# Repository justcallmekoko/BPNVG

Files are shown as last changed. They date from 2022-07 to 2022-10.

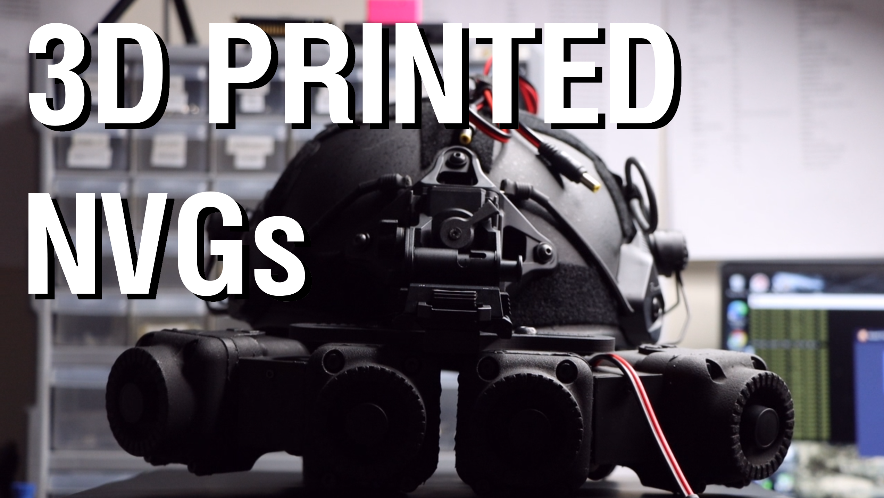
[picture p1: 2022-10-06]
BPNVG/images/thumnail1 - Copy.png

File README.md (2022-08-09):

# BPNVG

 This is the development repository for the PBNVG-project and all derivatives for joint development.
 
 We will also try to maintain extensive documentation of the project.

For more information and assembly instructions, check out the [wiki](https://github.com/justcallmekoko/BPNVG/wiki/bpnvg-v2-by-stubbs)

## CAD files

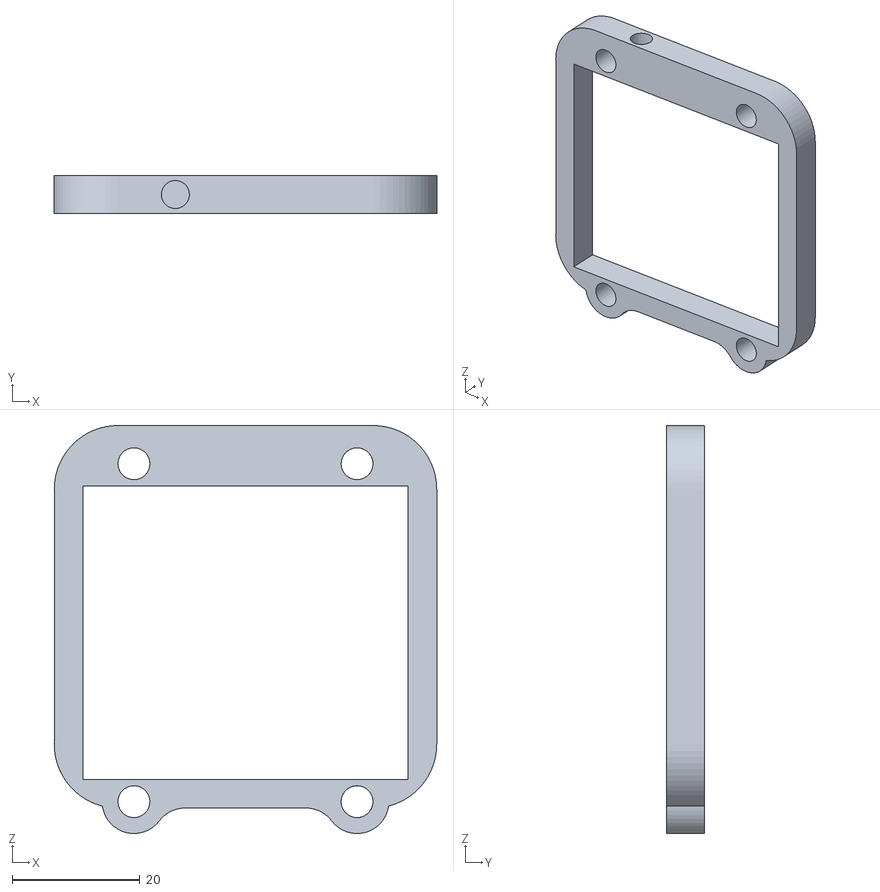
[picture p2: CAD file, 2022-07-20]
BPNVG/STLs/Gasket-Spacer_v3.stl
60.0 x 6.00 x 64.0

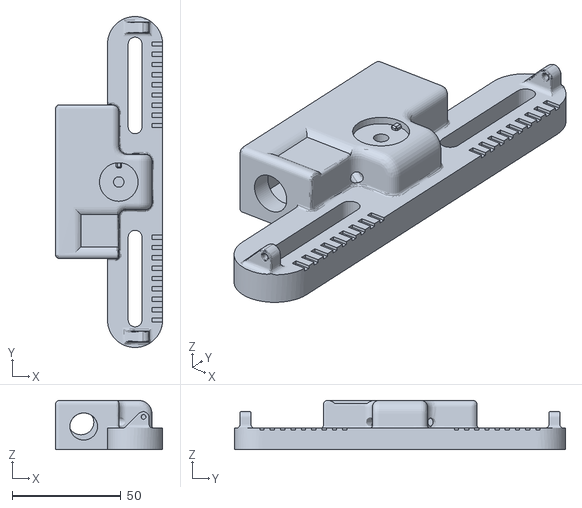
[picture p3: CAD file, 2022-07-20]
BPNVG/STLs/Powered Bridge_v3.3.stl
49.4 x 152.4 x 22.6

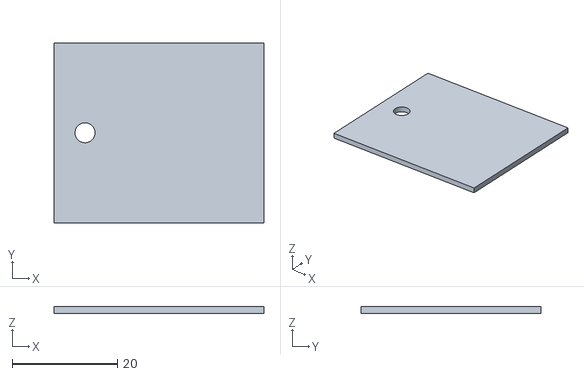
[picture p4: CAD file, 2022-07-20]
BPNVG/STLs/pano_COVER.stl
40.0 x 34.3 x 1.25

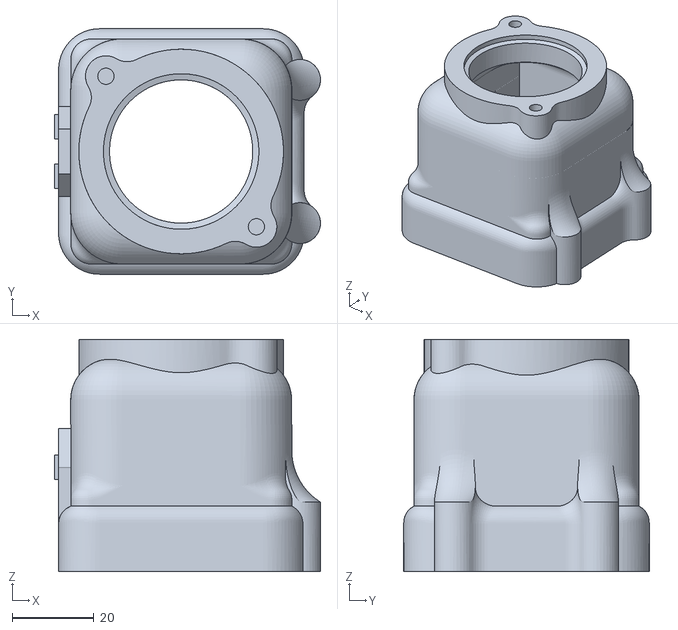
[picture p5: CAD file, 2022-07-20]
BPNVG/STLs/BPNVG_II_Single_monacle_body_SHORTY.stl
65.0 x 60.0 x 56.8

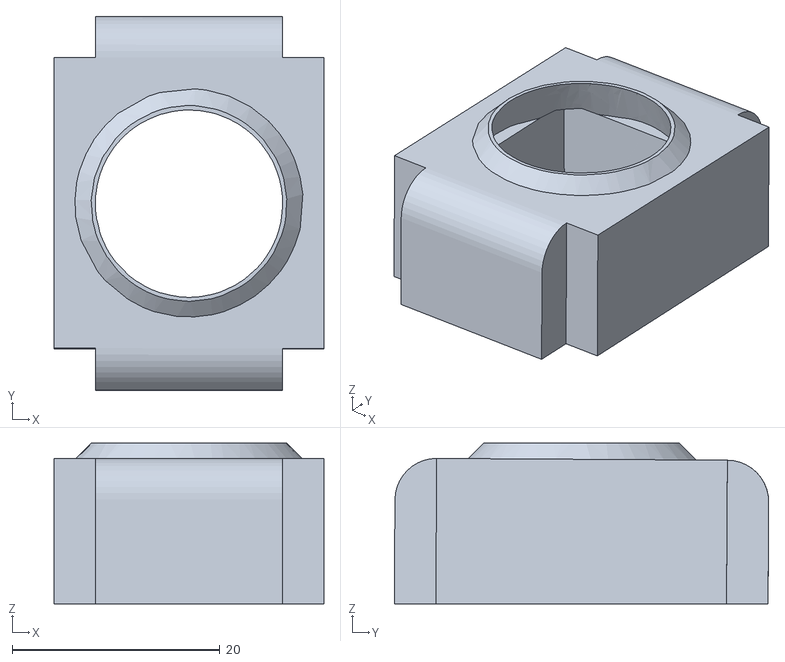
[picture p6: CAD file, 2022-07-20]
BPNVG/STLs/BPNVG Sensor Adaptor Night Cat 3 Fixed.stl
26.0 x 36.1 x 15.5

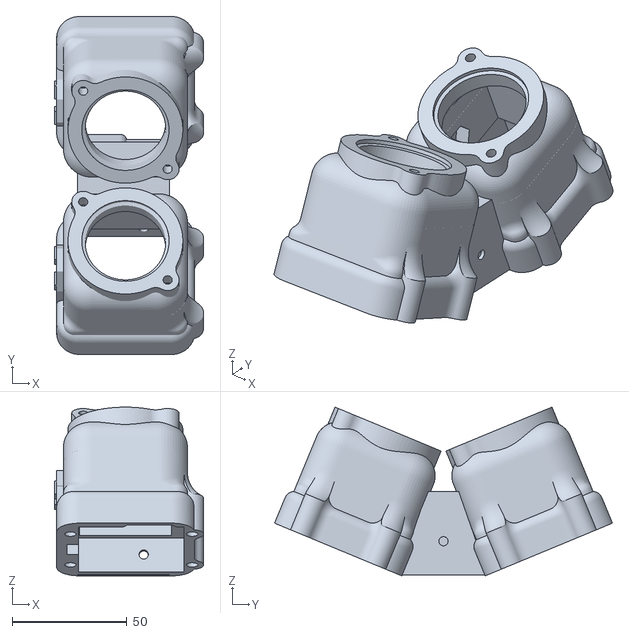
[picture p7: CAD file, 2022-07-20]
BPNVG/STLs/panoPANOpano.stl
65.0 x 147.1 x 73.5

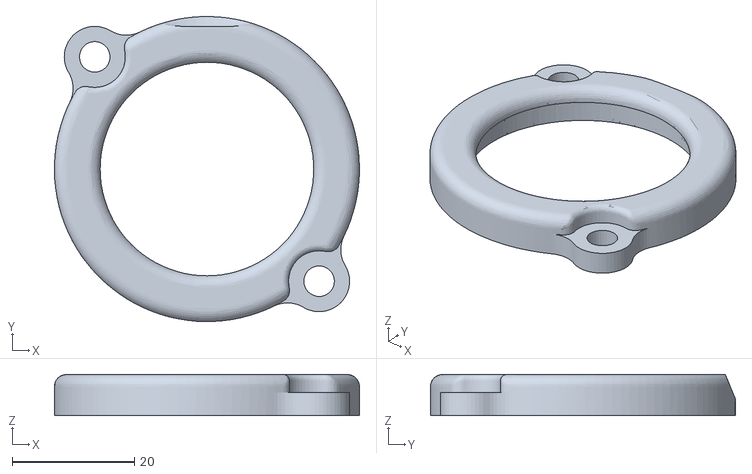
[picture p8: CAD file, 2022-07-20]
BPNVG/STLs/BPNVG Shorty Pano Lens Cover.stl
50.0 x 50.0 x 6.76

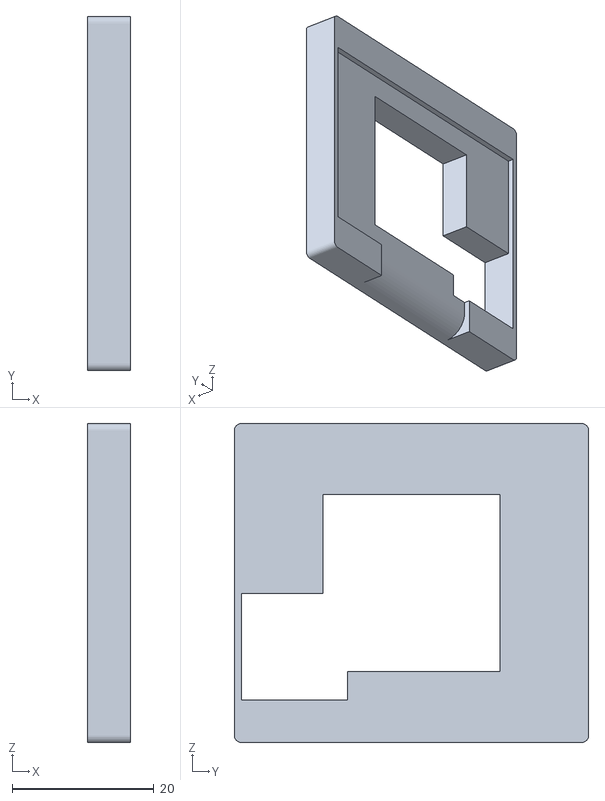
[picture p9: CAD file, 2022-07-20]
BPNVG/STLs/Internal Board Mount.stl
6.00 x 50.0 x 45.0

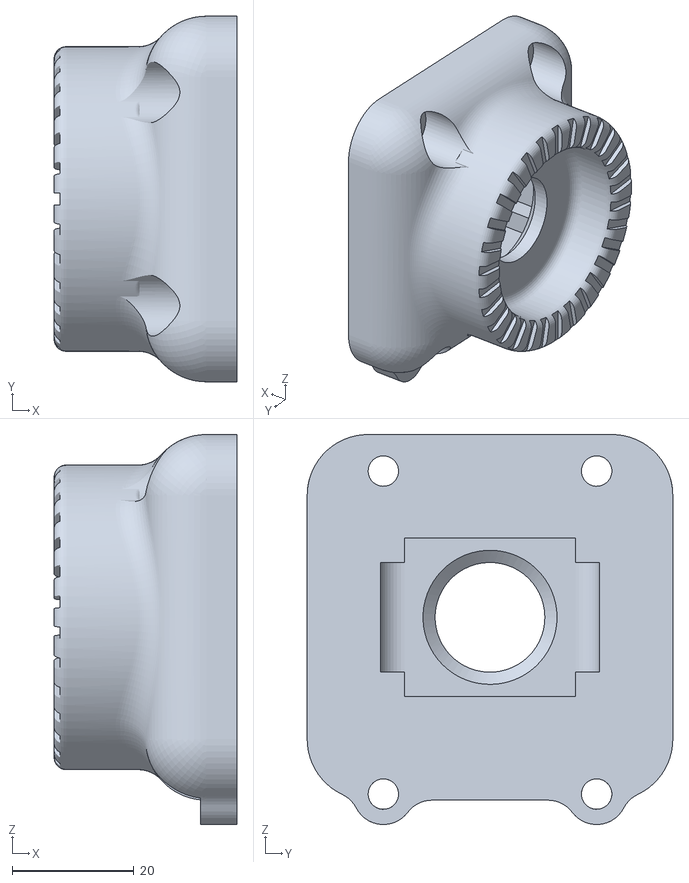
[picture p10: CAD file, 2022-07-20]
BPNVG/STLs/BPNVG II Sensor Mount.stl
30.0 x 60.0 x 64.0

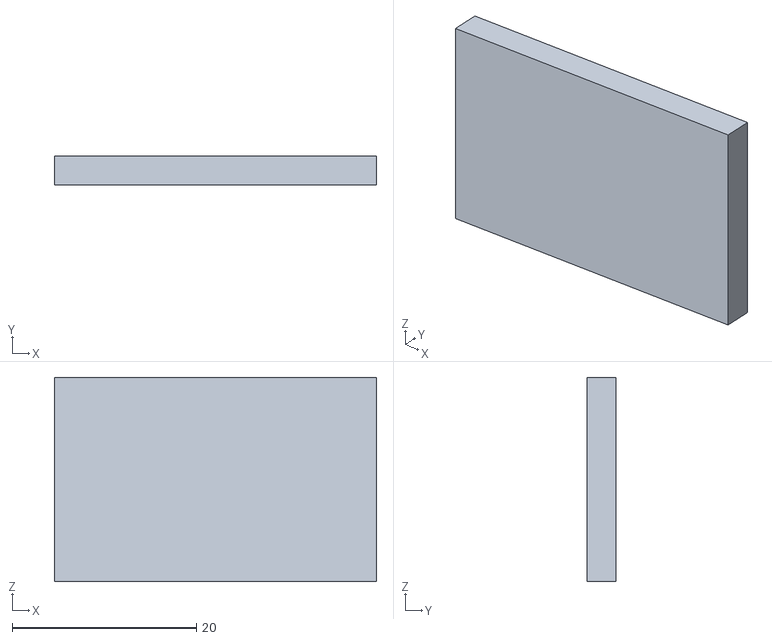
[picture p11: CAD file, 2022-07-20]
BPNVG/STLs/Abdeckung.stl
35.0 x 3.20 x 22.2

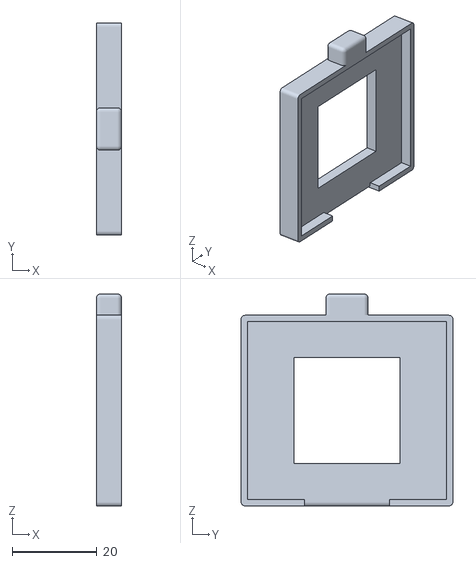
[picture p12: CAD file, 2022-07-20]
BPNVG/STLs/Internal Screen Mount.stl
6.00 x 50.0 x 50.0

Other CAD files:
BPNVG/STLs/LENSMODv2.stl

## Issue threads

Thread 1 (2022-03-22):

custom optics system for use with FLCOS system.

trisp3ar, 2022-03-22:
Requierements to be specified.

dom186, 2022-03-25:
Silicone on Vacuum chamber is curing should be cured by tomorrow.

dom186, 2022-03-25:
The second lens made with NOA61 looks better after I let it dry in air a few days than it did before. Weird fragments on what I think is the surface as well as embedded bubbles that are reducing image quality.

- Addressing the bubbles through vacuum degassing once chamber is cured.

- Not sure the cause of the other defects in the lens, maybe due to uneven curing maybe curing too fast?

- Not going to waste more of the expensive NOA61 going to go back to the cheap Chinese optical adhesive until I can develop a robust process and techniques for making lenses reliably. As stated by the researches the process for creating lenses should work the same no matter the adhesive or resin used.

- Once good optical clarity is achieved next step will be to design an biconvex spherical optic and make it. I'm thinking making an optic to replace the lens in the current BPNVG.

- Once that is achieved we should validate our process by making:
 - Aspheric lenses
 - Plano convex lenses
 - biconcave lenses
 - Doublet lenses

- Once our process has been validate for these lenses we could work on developing a method for controlling volume to create
 - maniscus lenses

dom186, 2022-04-05:
Taking a step back from trying to make a spherical optic. Am going to spend time working out the problems I'm having with optical quality. Going to focus on making flats on glass slides and trying different curing methods to see if that impacting the quality of the lens.

dom186, 2022-04-28:
Update: created some optics in air that looked good after curnf however when trying again in water it failed again. Thinking water is causing some reaction with the polymers and making it not possible to achieve a good surface finish.

Success in making optical flat using acrylic by hand polishing. Pivoting to thermoplastic lenses after the success. Created and currently printing some hard tooling to create spherical surfaces onto the lenses. Need to determine adhesive solution for the sand paper to adhere it to the hard tooling.

dom186, 2022-05-20:
Created first acrylic Plano convex lens.

Problems:
- Paper is too fragile to fining pad
 - Need to use polyester such as spunbond web or film backed adhesive. Or just purchase actual fining pads.
- adhesive used was too tacky and too flexible, almost like a gel. Was too difficult to cut into fining pad shape.
 - Need to preferably use a pressure sensitive rubber resin adhesive tape
- Hand polishing takes a long time and a lot of effort. Especially hand roughing the surface curvature with sand paper was very difficult and time consuming.
 - need to make at least some kind of spindle to help with rotating the optic.
 - would be nice to CNC the parts prior to fining and polishing
- Sphere center is not radially collinear with the axis of the lens
 - this problem could be alleviated with CNC machine also
- No way to measure accuracy of curvature
 - need a spherometer... preferably digital
- Lens still has visible scratches. Need to improve polishing process. Also need better protection on the finished side when polishing the opposite side.
 - need to purchase lens surface tape
 - need to semi automate the polishing process to "dial it in"
- Currently no way to measure focal length of lens.
 - need to research easiest method to measure focal length.

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

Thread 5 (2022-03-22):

optics system for use with FLCOS displays, using commercialy available parts

trisp3ar, 2022-03-22:

trisp3ar, 2022-03-22:
A clear image is visible when placing lenses in the following order:

FLCOS display - FLCOS display lens - [space: 0 mm] - double convex lens (f = 20...50 mm, tested) - [space: ~40 mm] - eye piece/ocular (WF10/20, tested)

trisp3ar, 2022-03-26:
### Test result #001

- source: FLCOS display + preinstalled lens
- eye piece	: WF10x/20
- Lens		: d = 16.5 mm, F = 30 mm

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

conclusion:
- distance between eye piece and display is very short, good option for integration
- the picture is very small and distorted, no option to consider for integration

trisp3ar, 2022-03-26:
### Test result #002
source: FLCOS display + preinstalled lens
eye piece	: WF10x/20
Lens		: d = 25 mm, F = 44.5 mm

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

conclusion:
- distance between eye piece and display is still short enough for integration
- the picture is still a little small but has not a lot distortion, still a little small for integration

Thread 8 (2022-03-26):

FLCOS brighness control

trisp3ar, 2022-03-26:
Implementation of brighness control for the FLCOS displays.
Brighness is controled by pulling the corresponding potentials to high.

cable colors for reference:
- Vcc : red (3.3 - 5 VDC)
- GND : black
- AV : orange
- AV GND : white
- brighness + : blue
- brighness - : green

Note: Implementation should be done on powered bridge for simultaneous adjustment on both displays. Blue, green and Vcc need to be routed through the cable system. Check for spacing in heatbreaks. PCB might be in order for two additional buttons.

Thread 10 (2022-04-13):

FPGA passive cooling solution

trisp3ar, 2022-04-13:
We need to figure out a way to cool the FPGA since it will be installed in a confined space. Maybe we can integrate a head spreader into the housing design. A small cooling solution should suffice tho.

GwenBunny, 2022-04-17:
i can start playing around in CAD. A friend of mine works in fabrication, maybe we can put together a prototype?

trisp3ar, 2022-04-17:
We don't have a hardware concept at this time. We are also trying to stay away from any kind of custom solution, if possible.
But if you want to look into it, you can search for good solutions available on the market.

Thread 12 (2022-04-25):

Add STLs for fully functional Binocular and Quad BPNVG

justcallmekoko, 2022-04-25:
Consolidate all STLs for assembling a fully functional set of binocular or quad BPNVGs and upload to this repo

trisp3ar, 2022-04-25:
You won't believe it but I'm actually wayting for Apollo to join the Git, so I can assign it to him.

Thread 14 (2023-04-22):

Double-convex lens buying tips

JSpiner, 2023-04-22:
Double-convex lens is pretty expensive.
In amazone, it costs $11.49 + extra delivery fee : [amazone link](https://www.amazon.com/gp/product/B01F9KXRX2/ref=ppx_yo_dt_b_search_asin_title?ie=UTF8&psc=1)
Lenses are about $4 each on AliExpress, which sells things cheaply, but there are no exact specifications, and shipping takes a long time.

I found a tip to get lenses easily, and cheaper.
Google Cardboard 2.0 features a 37mm double convex lens.
So if you buy one of these, you can get two 37mm or 42mm lenses for less than $7.
https://www.amazon.com/Multiple-Complete-Google-Cardboard-VR/dp/B08MW1NWF4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
Cardboard is much cheaper in Korea. You can get it for around $3.50.
You can also get it on AliExpress for a similar price.

It would be nice if this tip was added to the wiki.

JSpiner, 2023-04-22:
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
if you using 42mm lens, you should modify STL files.
The easiest way is to modify the lens cover.

This is sample : [lens_cover_for_42mm.zip](https://github.com/justcallmekoko/BPNVG/files/11299950/lens_cover_for_42mm.zip)
